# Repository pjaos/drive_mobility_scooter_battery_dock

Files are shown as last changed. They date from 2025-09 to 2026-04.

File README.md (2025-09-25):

# Drive Mobility Scooter Dock.
I built this dock for a drive mobility scooter battery. The dock uses the battery charger supplied with the mobility scooter to charge the battery.

A panel meter in the dock is used to show the voltage and current when charging.

The mobility scooter model that this project was generated for, is the [AutoFold Elite](https://drivedevilbiss.co.uk/our-products/powered-mobility-wheelchairs/scooters/folding-scooters/autofold-elite).

# Hardware
I 3D printed the case parts detailed in the case folder. These were created using FreeCad V1.0. There are three required parts, the top, base and the pogo pin panel. I printed these using Bambulab PETG-CF filament on a Bambulab X1C printer.

Assembled Dock

## Parts Required.
As well as the 3D printed parts the following parts are also required.

### Panel Meter
The panel meter is available on amazon and ebay.

A link to the panel meter used can be found @ https://www.amazon.co.uk/dp/B085QDY11D/ref=twister_B09YV7KRQB?_encoding=UTF8&th=1

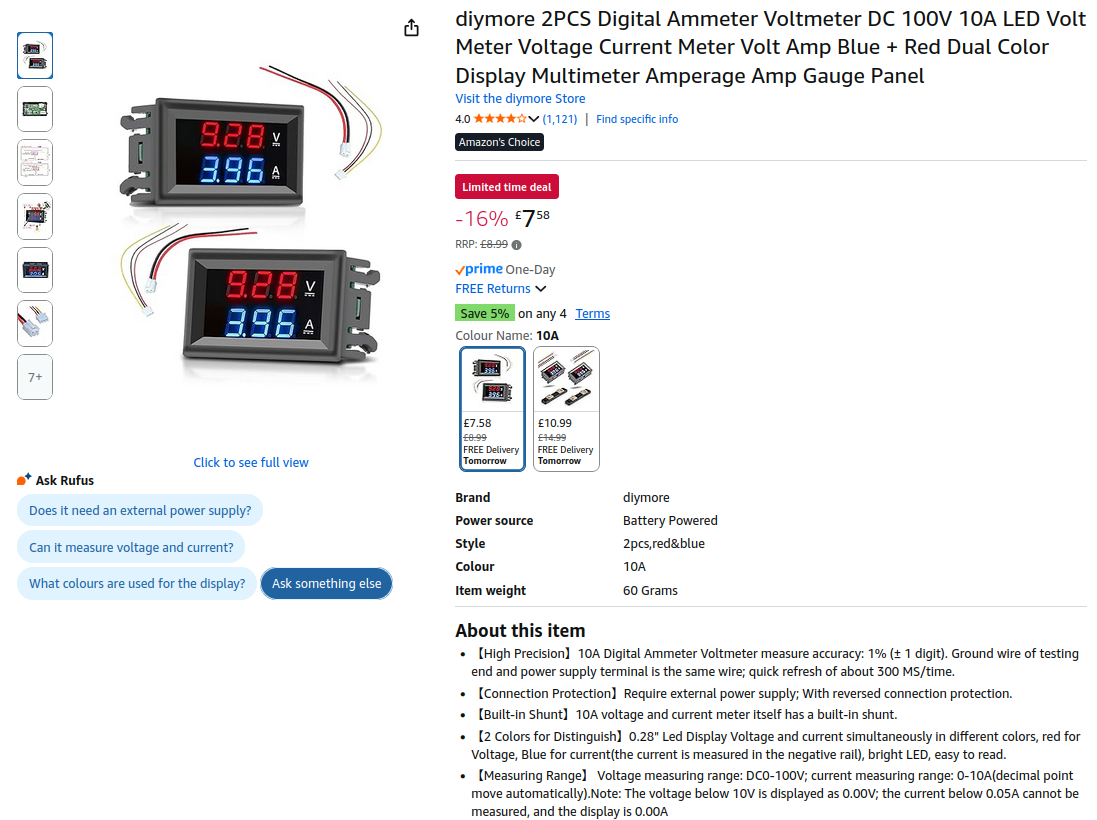
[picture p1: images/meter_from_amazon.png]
Panel Meter image 1


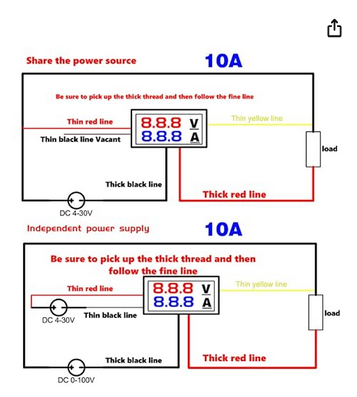
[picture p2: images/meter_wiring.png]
Panel Meter image 2


### XLR Connector
The XLR connector used can be found @ https://www.amazon.co.uk/dp/B07S6J8WVD?ref=ppx_yo2ov_dt_b_fed_asin_title

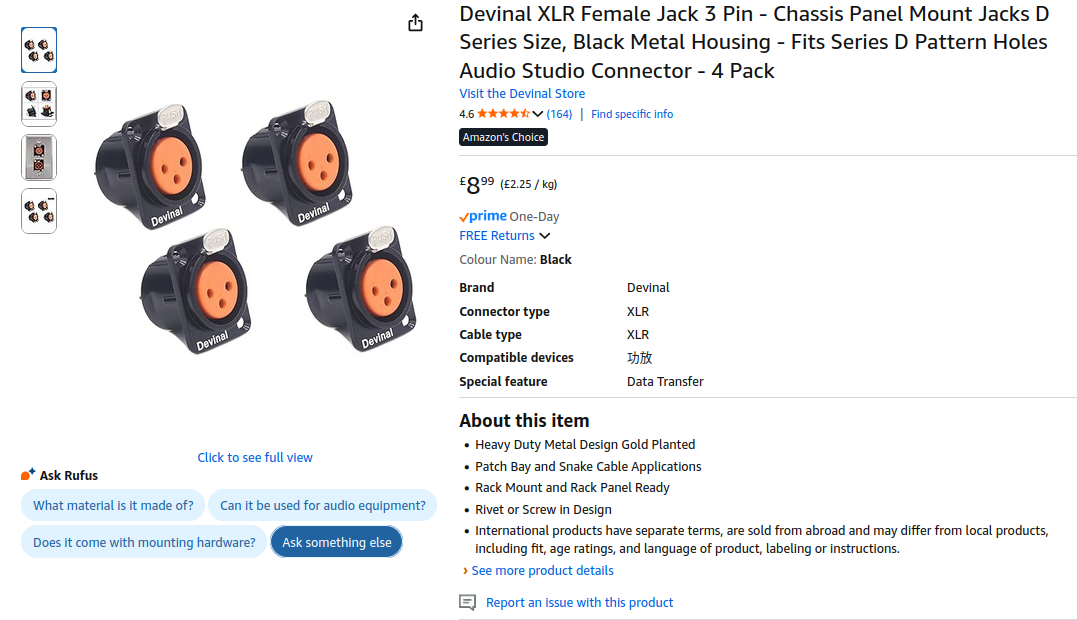
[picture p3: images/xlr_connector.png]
XLR Connector


### Fuse Holder
A single 20 mm panel mount fuse holder is required. These can be found on amazon or ebay. If the fuse holder you use do not have a flat to stop them turning in the hole you will need to file the flat off the hole in the case to fit them.
I fitted a 3A 20mm fuse to the fuse folder.

An example of these is shown below.

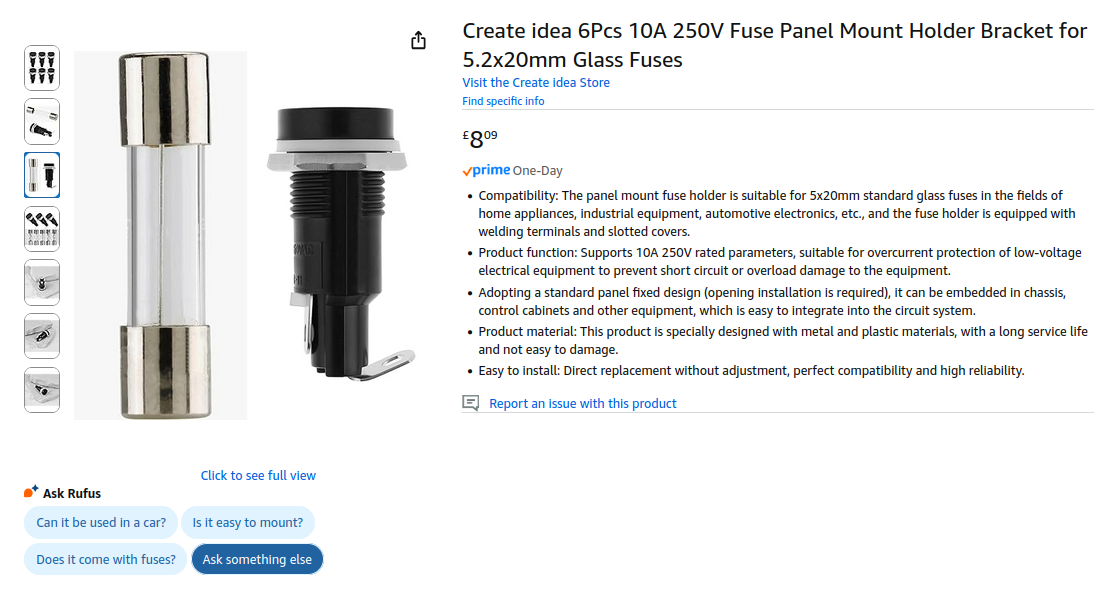
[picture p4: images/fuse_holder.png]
Fuse Holders


### H113 Pogo pins
These were purchased from Aliexpress

https://www.aliexpress.com/item/1005004524674158.html?spm=a2g0o.order_list.order_list_main.5.4b9118028GBk9F

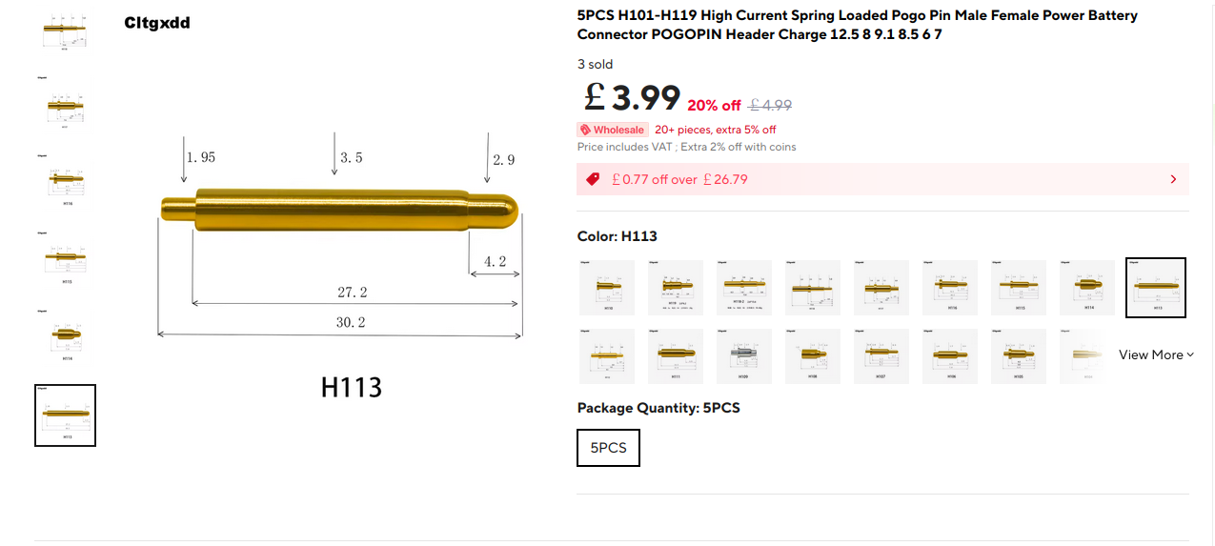
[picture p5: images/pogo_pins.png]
Pogo Pins


### SMBJ33A Device
The SMBJ33A TVS device can be found on amazon or ebay.

### M3 brass
Four M3 brass threaded inserts are required. These can be found on amazon or ebay.

An example of these is shown below.

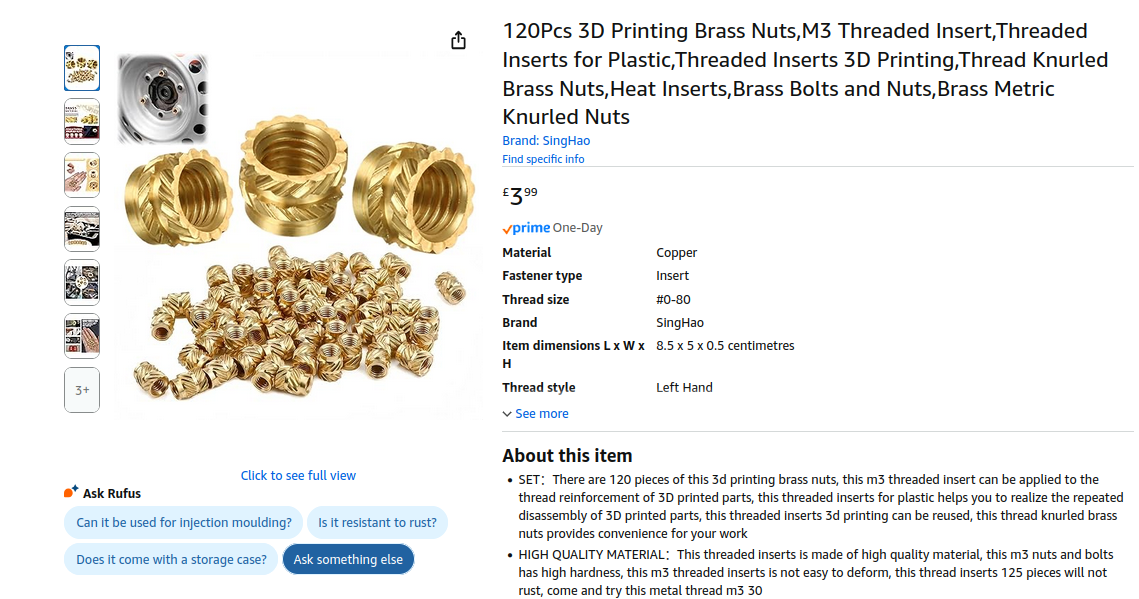
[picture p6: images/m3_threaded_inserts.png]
M3 Brass Threaded Inserts


## Assembly
The parts were connected as detailed in the following schematic.

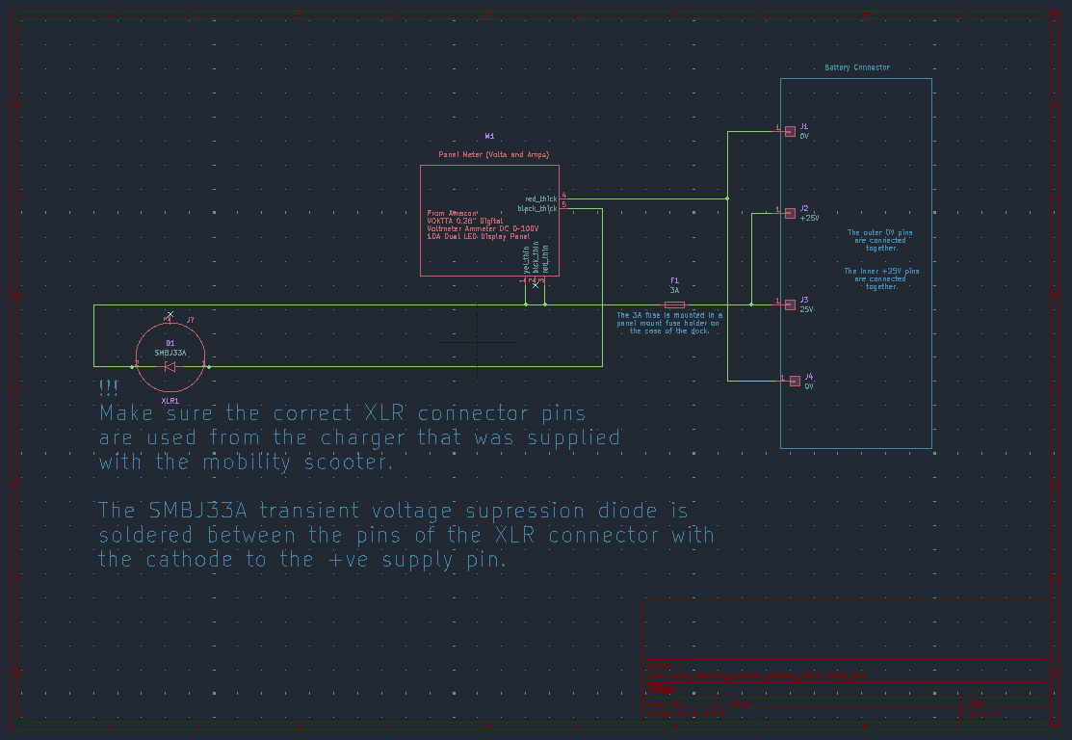
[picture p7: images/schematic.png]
Schematic


__It is important that the pogo pins are fitted to the pogo pin panel in the dock at the correct height. They should be fitted such that when compressed to 6mm (panel surface to top of pogo pin) there is still some travel left on the pogo pin. To do this use a 3.5mm drill to drill out the four holes on the pogo pin panel leaving the small hole at the bottom of the hole for the pogo pin connector to protrude through.__

Four M3 brass thread inserts were added to the 3D printed base part to allow four M3 x 10mm countersunk screws to be fitted (two on each side). I used black nylon screws. These hold the top to the base.

## Battery
The mobility scooter battery that the dock charges had the following label for identification.

Battery ID label

# License
This project is licensed under the Creative Commons Attribution 4.0 International License (CC BY 4.0).
See the LICENSE file for details.

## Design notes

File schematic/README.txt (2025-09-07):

The schematic is very simple and shows the connectivity from the 3 pin XLR
connector of the of the charger supplied with the scooter to the pogo pins 
on the dock and the panel meter.

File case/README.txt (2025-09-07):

These parts were printed in PETG-CF filament

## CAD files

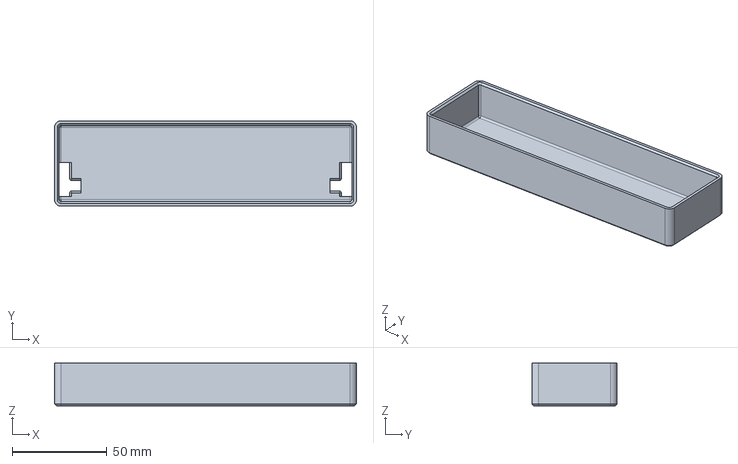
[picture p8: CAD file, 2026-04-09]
case/battery_cap.FCStd
159.0 x 45.0 x 22.5 mm

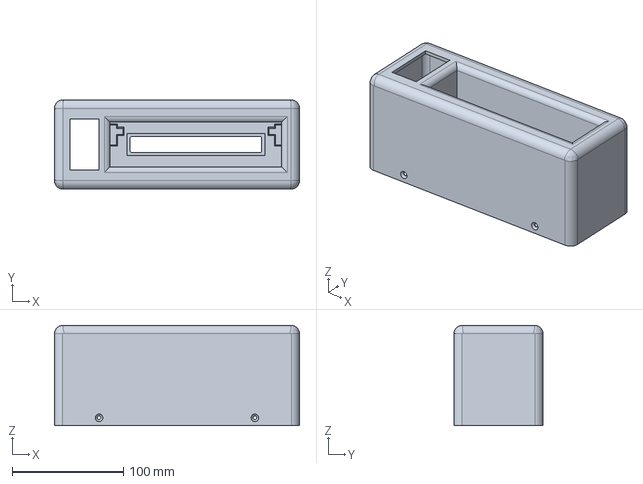
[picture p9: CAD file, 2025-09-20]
case/top.FCStd
220.0 x 80.0 x 90.0 mm

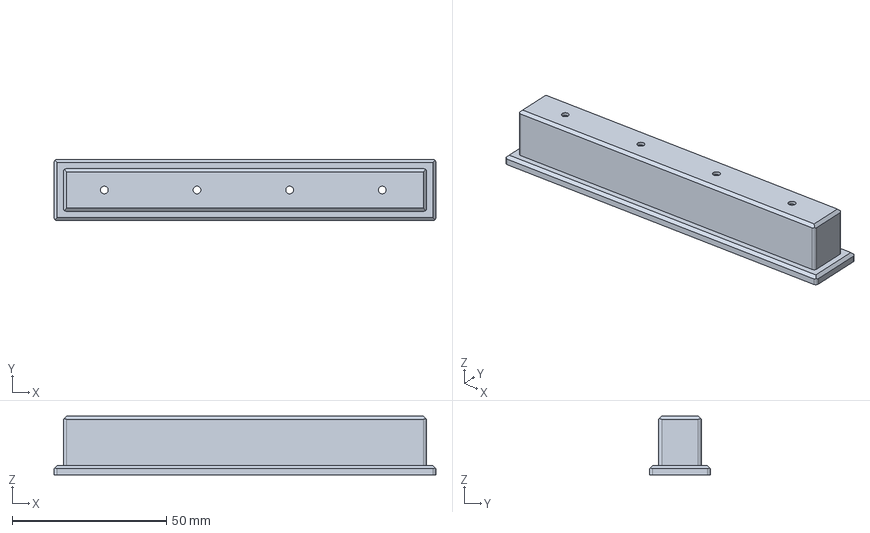
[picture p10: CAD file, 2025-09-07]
case/pogo_pin_panel.FCStd
123.7 x 19.8 x 19.0 mm

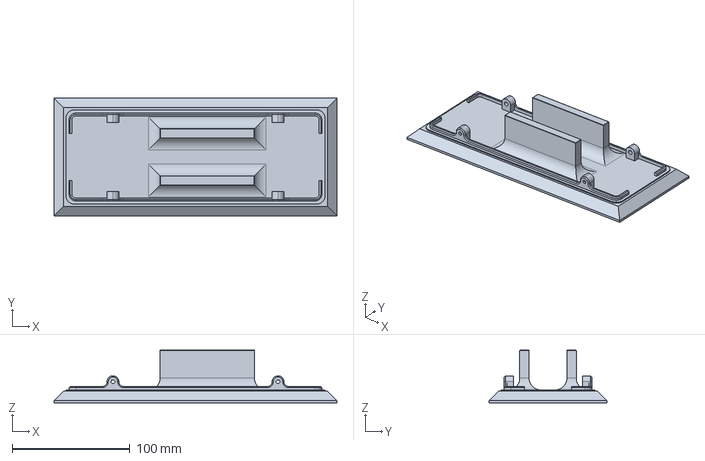
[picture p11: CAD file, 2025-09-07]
case/base.FCStd
240.0 x 100.0 x 44.8 mm

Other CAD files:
case/base.3mf
case/battery_cap.3mf
case/pogo_pin_panel.3mf
case/top.3mf

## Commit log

2025-09-07 Initial commit. The project not yet complete as it's not been fully built yet.
    [base.FCStd, drive_mobility_scooter_battery_dock.kicad_pcb, drive_mobility_scooter_battery_dock.kicad_sch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]
2025-09-07 Add files that can be imported int 3D printer slicer SW.
    [base.3mf, pogo_pin_panel.3mf, top.3mf]
2025-09-17 - Add fuse. - Update documentation.
    [drive_mobility_scooter_battery_dock.kicad_sch]
2025-09-17 Add fuse holder doc.
2025-09-18 Add TVS device.
    [drive_mobility_scooter_battery_dock.kicad_sch]
2025-09-18 Add image of schematic.
2025-09-18 Add hole in top for fuseholder.
    [top.3mf, top.FCStd]
2025-09-20 - Close battery locating lug holes so to stop dirt etc dropping through inside the case. - Increase the countersunk hole size so that screws don't protrude.
    [top.3mf, top.FCStd]
2026-04-09 Add plastic cap for battery when stored outside scooter to ensure nothing comes into contact with the electrical contacts on the battery.
    [battery_cap.3mf, battery_cap.FCStd]
